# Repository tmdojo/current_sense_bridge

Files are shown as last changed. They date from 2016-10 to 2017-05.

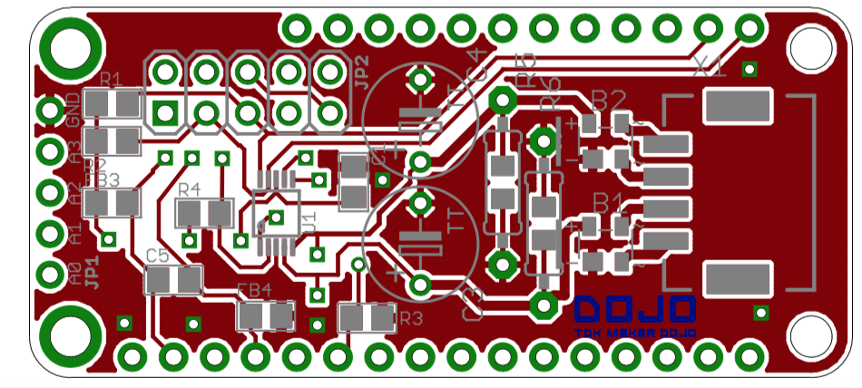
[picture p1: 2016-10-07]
TMdojo-Current-Sensor_v0p2_layoutA.png

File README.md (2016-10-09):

# Diode bridge rectifier and ADC break out board for clamp current sensors

This is designed for clamp current sensors such as:

TDK Corporation CCT261631-30-06-02
http://www.digikey.com/product-detail/en/tdk-corporation/CCT261631-30-06-02/445-172911-ND/5126210

The board is designed to fit nicely on Adafruit Feather line of products.
It also fit on Raspberry Pi although only ten pins are brokenout.
Mount it on a breadboard and you could combine it with many other microcontrollers such as Arduino Uno, MBED, etc

ADC part of the schematics and symbols are derived from the Adafruit 12 and 16 bit I2C ADC's with PGA.
https://github.com/adafruit/ADS1X15-Breakout-Board-PCBs

Please find the original readme text attached below.

----
This is the PCB for the Adafruit 12 and 16 bit I2C ADC's with PGA
Format is EagleCAD schematic and board layout

For more details, check out the product page at

-----> http://adafruit.com/products/1083
-----> http://adafruit.com/products/1085

Adafruit invests time and resources providing this open source design,
please support Adafruit and open-source hardware by purchasing
products from Adafruit!

Designed by Adafruit Industries.  
Creative Commons Attribution, Share-Alike license, check license.txt for more information
All text above must be included in any redistribution

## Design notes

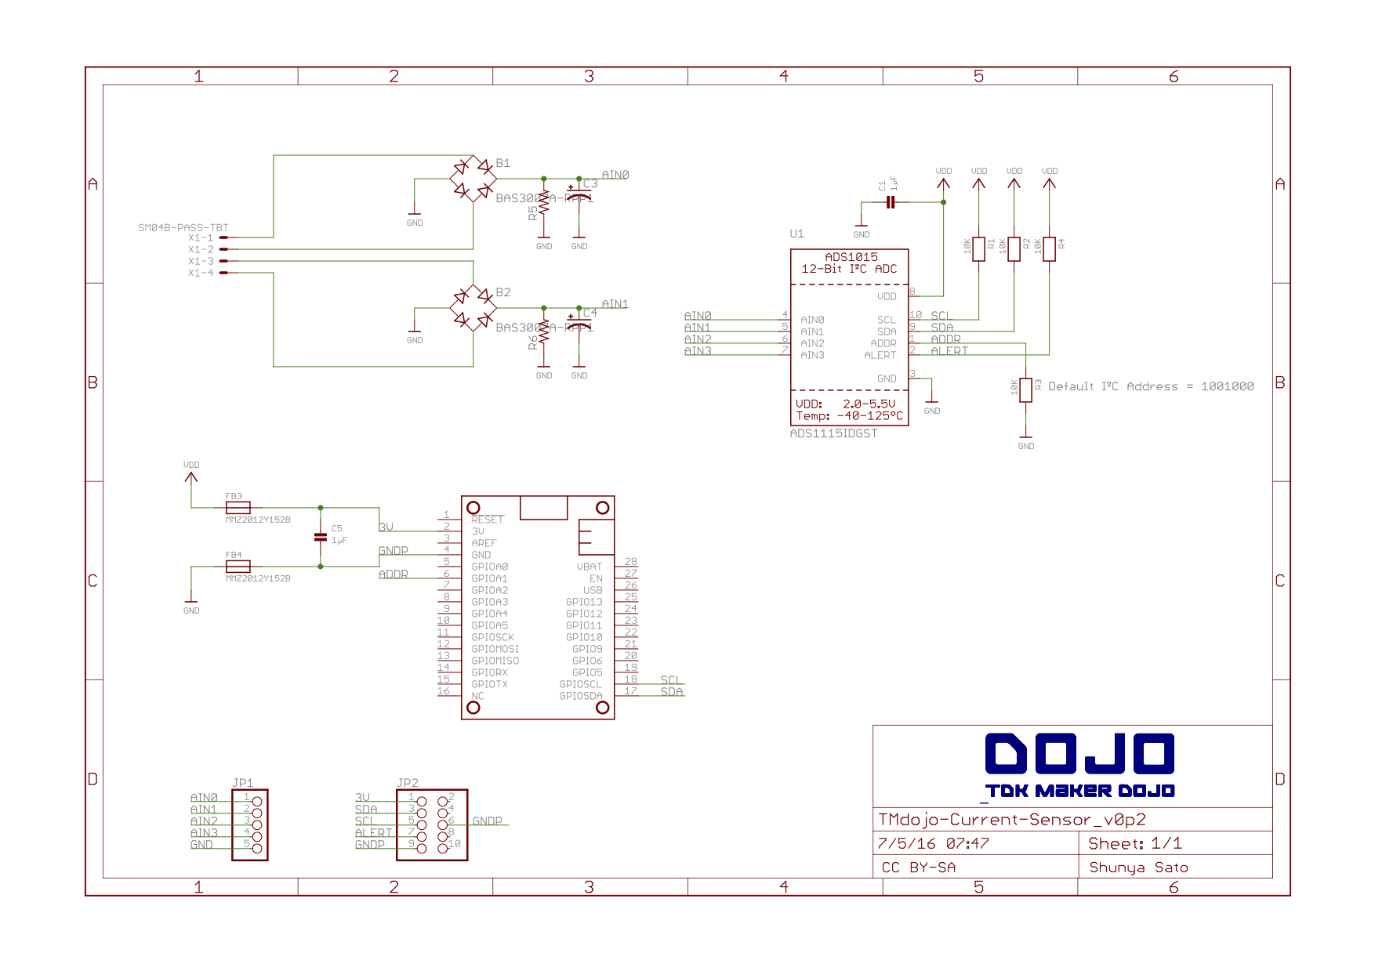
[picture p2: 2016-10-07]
TMdojo-Current-Sensor_v0p2_schematics.png

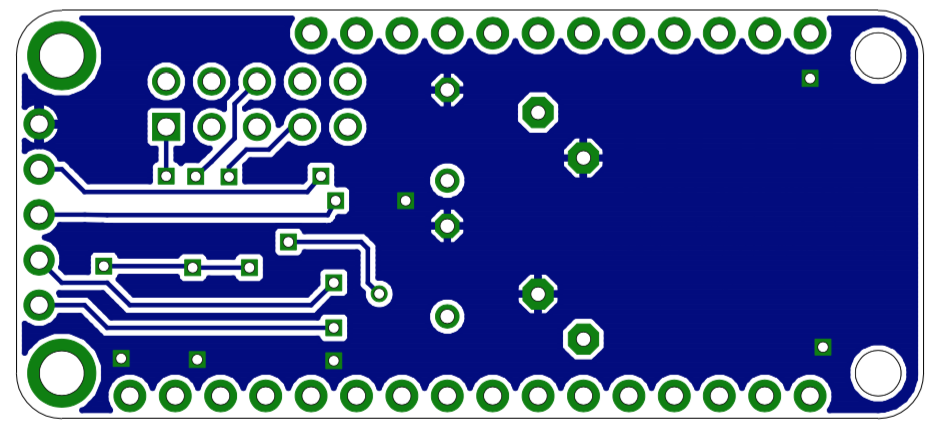
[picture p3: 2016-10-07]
TMdojo-Current-Sensor_v0p2_layoutB.png

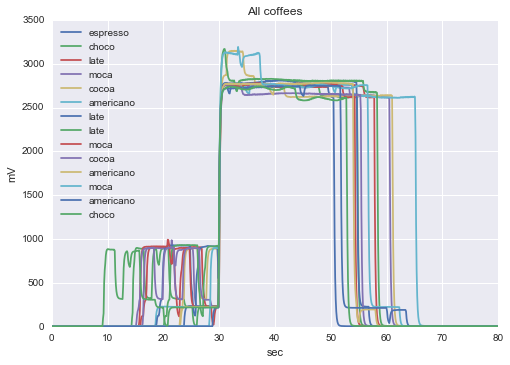
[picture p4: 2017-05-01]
images/coffee.png

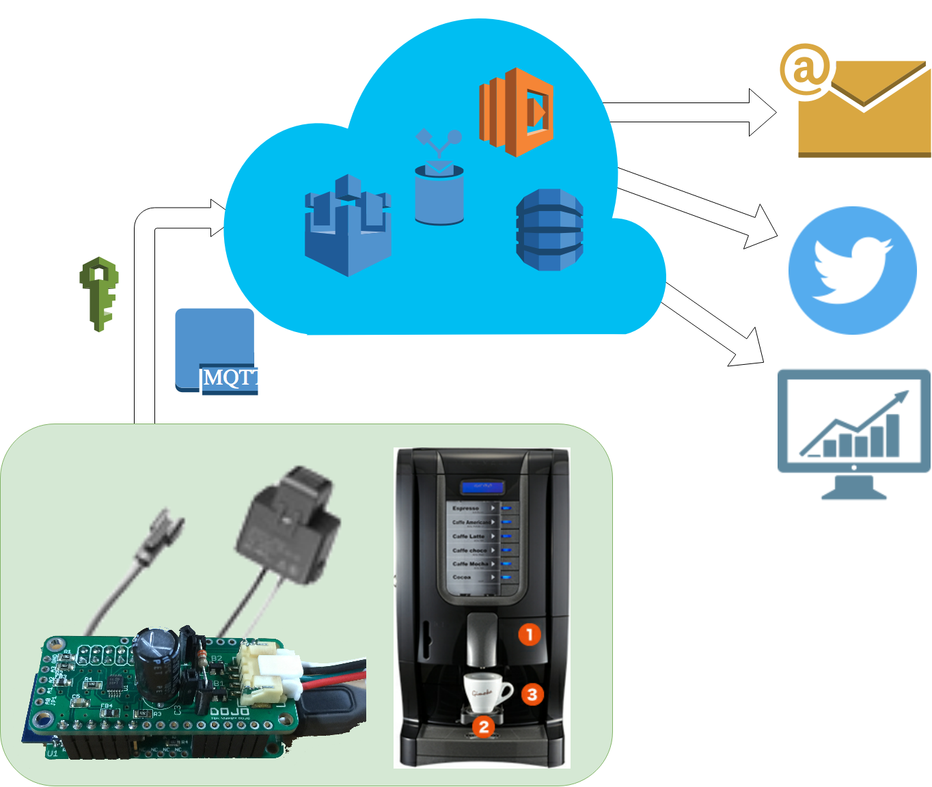
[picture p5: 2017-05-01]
images/current_monitoring.png

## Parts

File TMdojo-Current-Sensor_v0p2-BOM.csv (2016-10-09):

Part/Designator | Manufacture Part Number/Seeed SKU | Quantity | Digikey Part Number | Digikey Web Link | Note
U1 | ADS1015IDGST | 1 | 296-25227-1-ND | http://www.digikey.com/product-detail/en/texas-instruments/ADS1015IDGST/296-25227-1-ND/2174997
X2 | SM04B-PASS-TBT(LF)(SN) | 1 | 455-2645-1-ND | http://www.digikey.com/product-detail/en/jst-sales-america-inc/SM04B-PASS-TBT(LF)(SN)/455-2645-1-ND/2773441
B1, B2 | BAS 3007A-RPP E6327 | 2 | BAS3007A-RPPE6327INCT-ND | http://www.digikey.com/product-search/en/discrete-semiconductor-products/bridge-rectifiers/1377580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
C1, C5 | CC0805KKX7R8BB105/302010179 | 2 | 311-1456-1-ND | http://www.digikey.com/product-search/en/capacitors/ceramic-capacitors/131083?k=CC0805KKX7R8BB105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 | 1uF 0805
R1, R2, R3, R4 | RC0805FR-0710KL/301010361 | 4 | 311-10.0KCRCT-ND | http://www.digikey.com/product-search/en/resistors/chip-resistor-surface-mount/65769?k=RC0805FR-0710KL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 | 10k 0805
FB3, FB4 | MMZ2012Y152BT000 | 2 | 445-1560-1-ND | http://www.digikey.com/product-detail/en/tdk-corporation/MMZ2012Y152BT000/445-1560-1-ND/571890 | FERRITE BEAD 1.5 KOHM 0805 1LN
R5, R6 | Non-Fit 300 Ohm | 2
C3, C4 | Non-Fit 220uF | 2 | 493-6096-1-ND | https://www.digikey.jp/product-detail/ja/nichicon/UVR1C221MED1TA/493-6096-1-ND/3438470 | 7mmで220uFだと耐圧が16Vになっちゃう。25Vだと150uFが最大。経8mmだと220uFで25vある。
JP1, JP2, MS1 | Non-Fit | 0

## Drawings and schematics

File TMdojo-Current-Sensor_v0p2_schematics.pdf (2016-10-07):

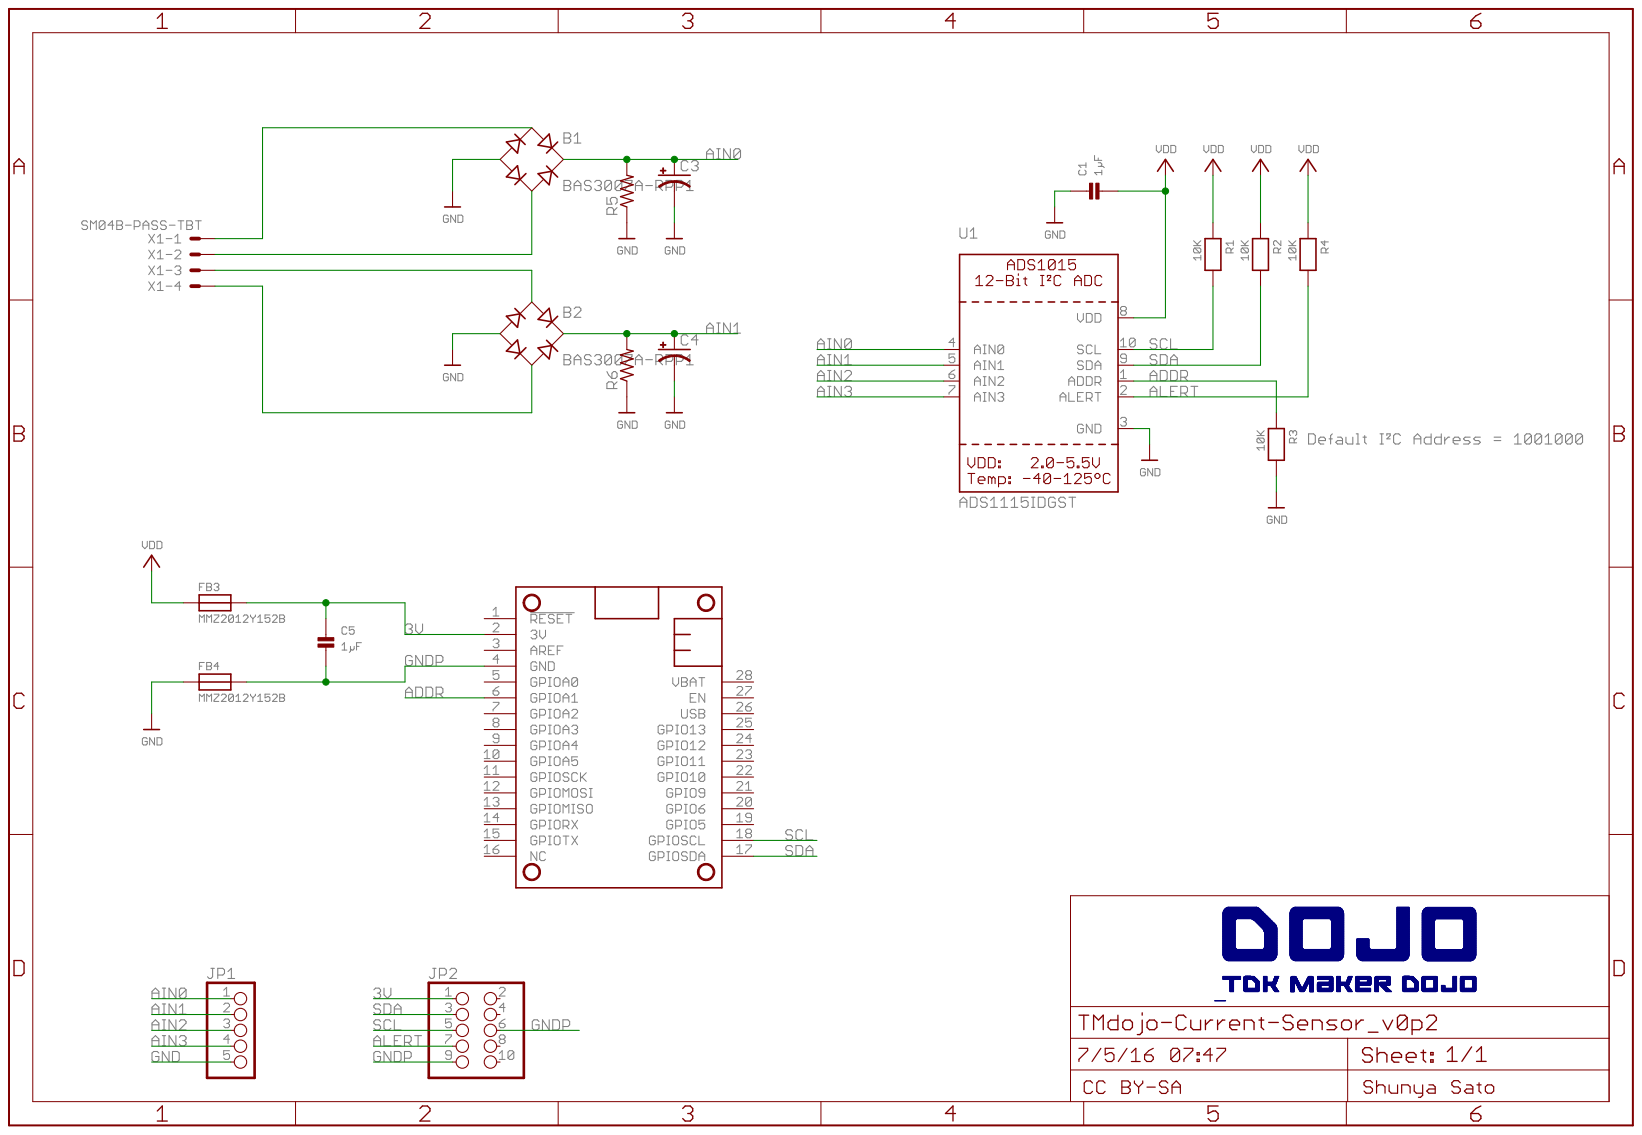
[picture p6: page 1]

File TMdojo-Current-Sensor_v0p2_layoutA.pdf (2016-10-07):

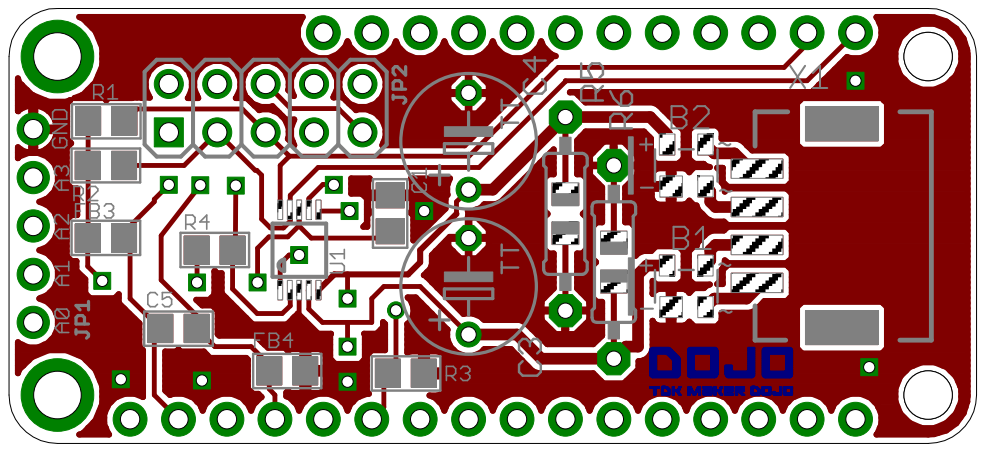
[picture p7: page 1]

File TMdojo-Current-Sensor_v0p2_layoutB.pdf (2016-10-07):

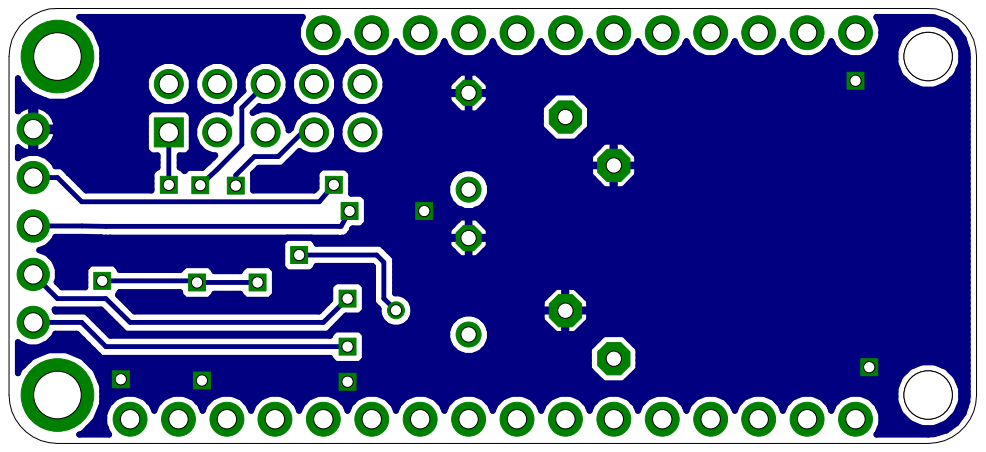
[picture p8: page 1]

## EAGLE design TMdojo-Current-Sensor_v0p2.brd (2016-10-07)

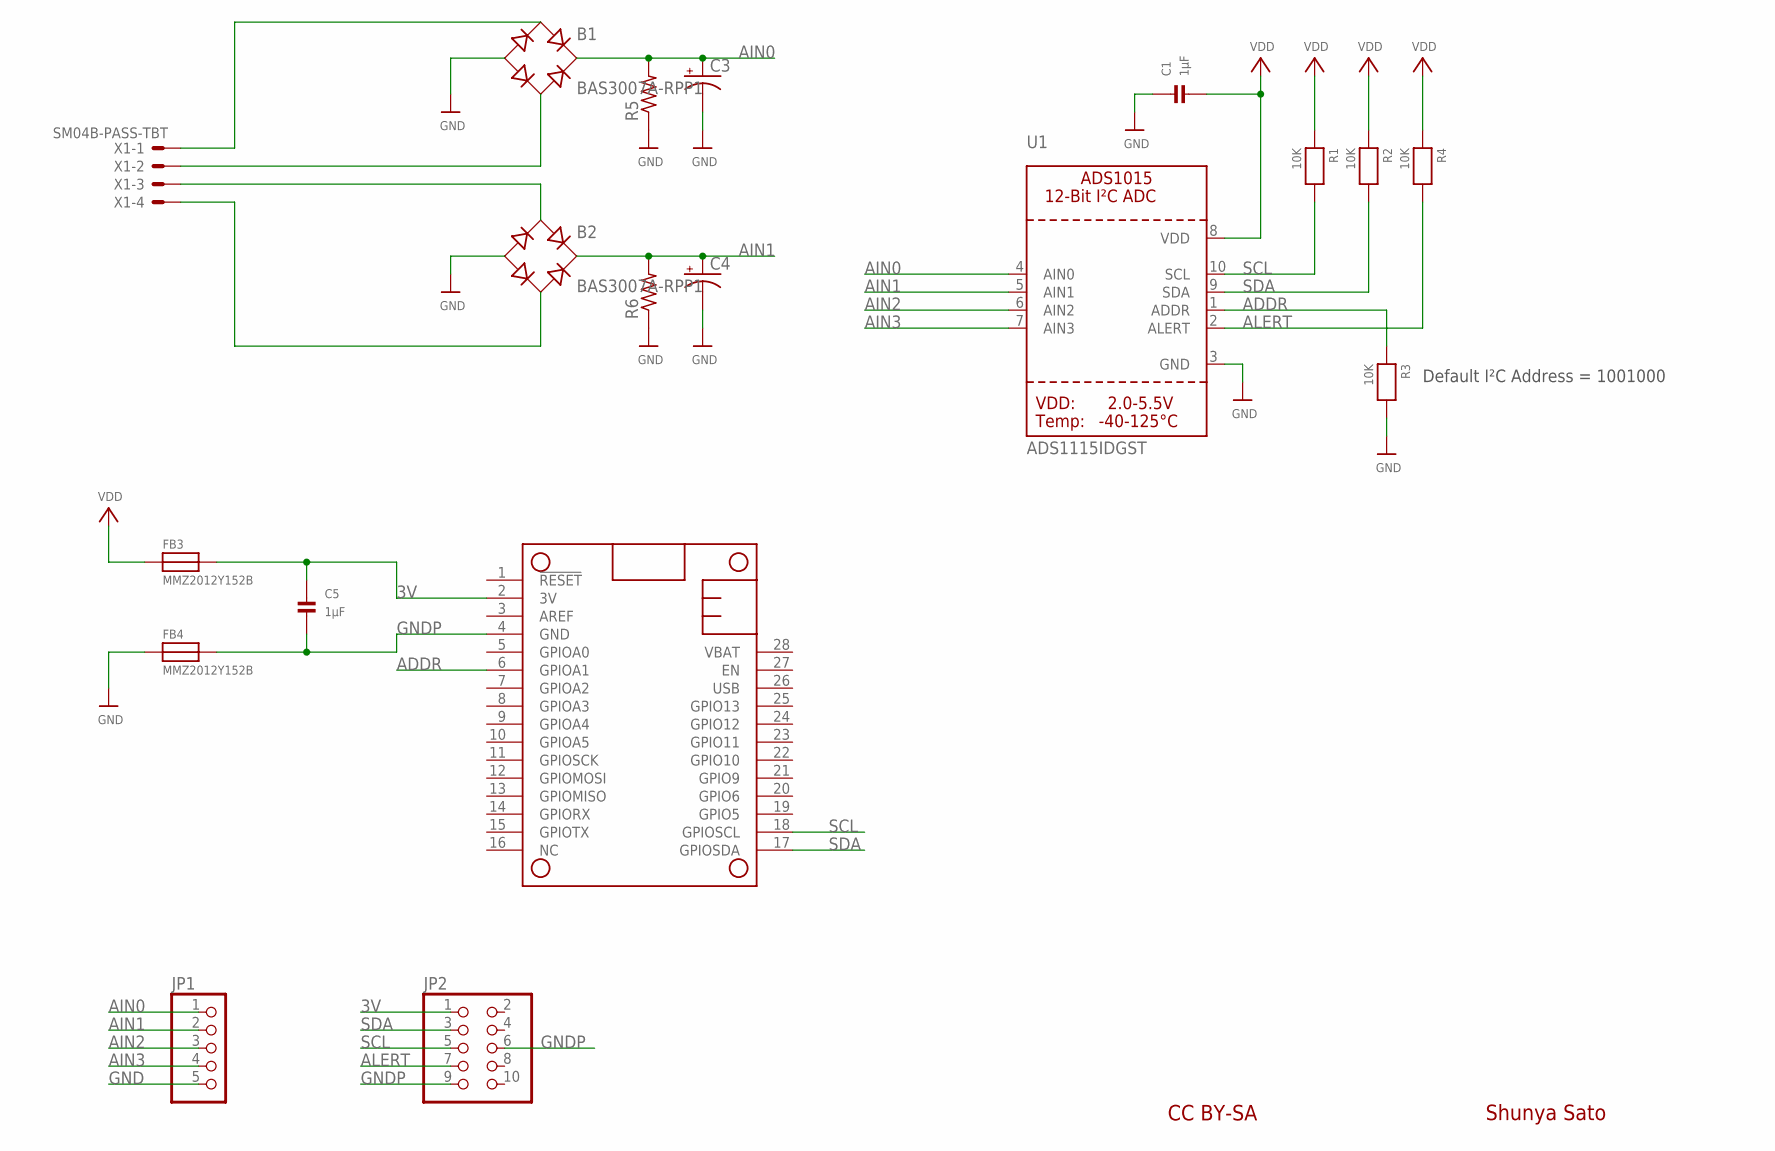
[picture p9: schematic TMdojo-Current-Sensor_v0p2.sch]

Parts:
B1, B2: BAS3007A-RPP1; SOT143
C1, C5: 1µF; 0805
C3, C4: CPOL-USTT5D7; TT5D7
FB3, FB4: MMZ2012Y152B; 0805
JP1: HEADER-1X5ROUND; 1X05_ROUND
JP2: HEADER-2X5; 2X05
MS1: FEATHERWING
R1, R2, R3, R4: 10K; 0805
R5, R6: R-US_FLIPFLOP; 0805-THM
U1: ADS1115IDGST; MSOP10
X1: SM04B-PASS-TBT

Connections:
3V: C5.1, FB3.2, JP2.1, MS1.2 (3V)
ADDR: MS1.6 (GPIOA1), R3.1, U1.1 (ADDR)
AIN0: B1.+, C3.+, JP1.1, R5.2, U1.4 (AIN0)
AIN1: B2.+, C4.+, JP1.2, R6.2, U1.5 (AIN1)
AIN2: JP1.3, U1.6 (AIN2)
AIN3: JP1.4, U1.7 (AIN3)
ALERT: JP2.7, R4.2, U1.2 (ALERT)
GND: B1.-, B2.-, C1.1, C3.-, C4.-, FB4.1, JP1.5, R3.2, R5.1, R6.1, U1.3 (GND)
GNDP: C5.2, FB4.2, JP2.6, JP2.9, MS1.4 (GND)
unnamed: B1.~1 (AC1), X1.1
unnamed: B1.~2 (AC2), X1.2
unnamed: B2.~1 (AC1), X1.3
unnamed: B2.~2 (AC2), X1.4
SCL: JP2.5, MS1.18 (GPIOSCL), R1.2, U1.10 (SCL)
SDA: JP2.3, MS1.17 (GPIOSDA), R2.2, U1.9 (SDA)
VDD: C1.2, FB3.1, R1.1, R2.1, R4.1, U1.8 (VDD)

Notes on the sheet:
Default I²C Address = 1001000
Shunya Sato
CC BY-SA

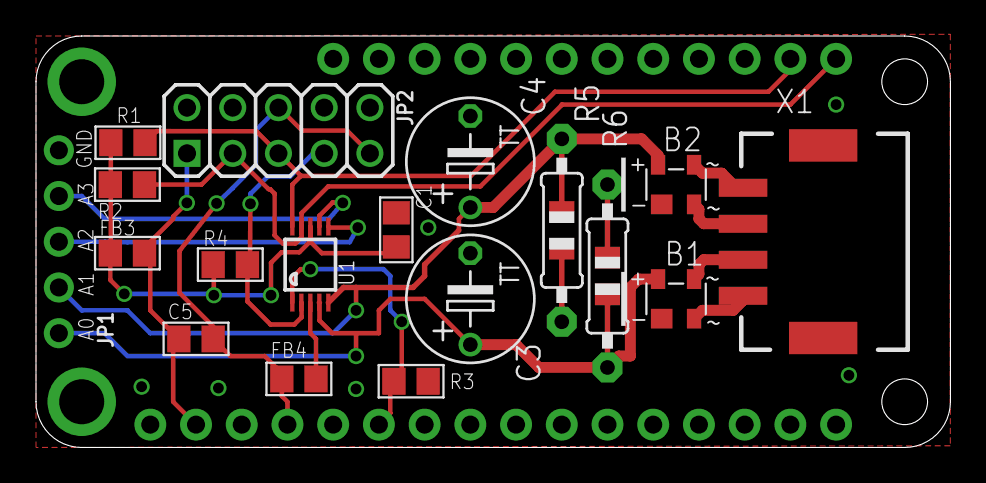
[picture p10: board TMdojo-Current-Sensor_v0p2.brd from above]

Board: 2 copper layers, 50.8 x 22.9 mm, 19 parts (0 on the bottom side), 16 nets.

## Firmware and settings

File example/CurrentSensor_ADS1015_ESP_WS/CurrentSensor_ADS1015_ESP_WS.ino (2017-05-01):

/*
current_sense_bridge example code

This code demonstrates how to read data from ADS1015 ADC on the current_sense_bridge board.

You need to install ADS1X15 Arduino library written by Adafruit Industries
https://github.com/adafruit/Adafruit_ADS1X15
Significant portion of this code was taken from the example included in the library.

This code is largely based on WebSocketServer_LEDcontrol.ino
https://github.com/Links2004/arduinoWebSockets

Run ESP-8266 with this sketch, access from your Mac or iPhone at this URL
http://esp-ct.local
You would see live update of data with plot

Author: Shunya Sato

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
*/

// #include <Arduino.h>

#include <ESP8266WiFi.h>
#include <ESP8266WiFiMulti.h>
#include <WebSocketsServer.h>
#include <ESP8266WebServer.h>
#include <ESP8266mDNS.h>
#include <Hash.h>

#include <Wire.h>
#include <Adafruit_ADS1015.h>
#include "Timer.h"

#define USE_SERIAL Serial


ESP8266WiFiMulti WiFiMulti;

ESP8266WebServer server = ESP8266WebServer(80);
WebSocketsServer webSocket = WebSocketsServer(81);

void webSocketEvent(uint8_t num, WStype_t type, uint8_t * payload, size_t lenght) {

    switch(type) {
        case WStype_DISCONNECTED:
            USE_SERIAL.printf("[%u] Disconnected!\n", num);
            break;
        case WStype_CONNECTED: {
            IPAddress ip = webSocket.remoteIP(num);
            USE_SERIAL.printf("[%u] Connected from %d.%d.%d.%d url: %s\n", num, ip[0], ip[1], ip[2], ip[3], payload);

            // send message to client
            webSocket.sendTXT(num, "Connected");
        }
            break;
        case WStype_TEXT:
            USE_SERIAL.printf("[%u] get Text: %s\n", num, payload);
            break;
    }

}

Timer t;
//Adafruit_ADS1115 ads;
Adafruit_ADS1015 ads;

// const float multiplier = 3.0F; /* ADS1015  @ 2/3x gain +/- 6.144V (12-bit results) */
const float multiplier = 2.0F; /* ADS1015  @ 1x gain   +/- 4.096V (12-bit results) */
// const float multiplier = 1.0F; /* ADS1015  @ 2x gain   +/- 2.048V (12-bit results) */
// const float multiplier = 0.5F; /* ADS1015  @ 4x gain   +/- 1.024V (12-bit results) */
// const float multiplier = 0.25F; /* ADS1015  @ 8x gain   +/- 0.512V (12-bit results) */
// const float multiplier = 0.125F; /* ADS1015  @ 16x gain  +/- 0.256V (12-bit results) */

void readADC(){
  int16_t adc0;
  int16_t adc1;

  adc0 = ads.readADC_SingleEnded(0);
  adc1 = ads.readADC_SingleEnded(1);

  Serial.print(millis());
  Serial.print(", ");
  Serial.print(adc0);
  Serial.print(", ");
  Serial.print(adc0 * multiplier);
  Serial.print(", ");
  Serial.print(adc1);
  Serial.print(", ");
  Serial.println(adc1 * multiplier);

  String tmp = String(adc1*multiplier);

  webSocket.broadcastTXT(tmp);
  
}

void setup() {
    USE_SERIAL.begin(115200);

    USE_SERIAL.println();
    USE_SERIAL.println();
    USE_SERIAL.println();

    for(uint8_t t = 4; t > 0; t--) {
        USE_SERIAL.printf("[SETUP] BOOT WAIT %d...\n", t);
        USE_SERIAL.flush();
        delay(1000);
    }

    WiFiMulti.addAP(“SSID", “password");
    WiFiMulti.addAP(“SSID2", “password");
    
    while(WiFiMulti.run() != WL_CONNECTED) {
        delay(100);
    }

    // start webSocket server
    webSocket.begin();
    webSocket.onEvent(webSocketEvent);

    if(MDNS.begin("esp-ct")) {
        USE_SERIAL.println("MDNS responder started");
    }

    // handle index
    server.on("/", []() {
        // send index.html
        server.send(200, "text/html", "<html><head><script type='text/javascript' src='https://cdnjs.cloudflare.com/ajax/libs/smoothie/1.27.0/smoothie.js'></script></head><body>Current sensor reading: <span id='nowvalue'></span><br/><br/><canvas id='mycanvas' width='400' height='100'></canvas><script>var smoothie = new SmoothieChart({  grid: { strokeStyle:'rgb(125, 125, 125)', fillStyle:'rgb(60, 0, 0)',          lineWidth: 1, millisPerLine: 250, verticalSections: 6, },  labels: { fillStyle:'rgb(255, 255, 0)' }});smoothie.streamTo(document.getElementById('mycanvas'), 100 /*delay*/);var line1 = new TimeSeries();setInterval(function() {  line1.append(new Date().getTime(), Math.random());}, 1000);smoothie.addTimeSeries(line1,  { strokeStyle:'rgb(0, 255, 0)', fillStyle:'rgba(0, 255, 0, 0.4)', lineWidth:3 });var connection = new WebSocket('ws://'+location.hostname+':81/', ['arduino']);connection.onopen = function () {  connection.send('Connect ' + new Date());};connection.onerror = function (error) {  console.log('WebSocket Error ', error);};connection.onmessage = function (e) {  console.log('Server: ', e.data);  line1.append(new Date().getTime(), parseFloat(e.data));  document.getElementById('nowvalue').innerHTML = e.data;};</script></body></html>");
    });

    server.begin();

    // Add service to MDNS
    MDNS.addService("http", "tcp", 80);
    MDNS.addService("ws", "tcp", 81);

  //Serial.println("Getting single-ended readings from AIN0..3");
  //Serial.println("ADC Range: +/- 6.144V (1 bit = 3mV/ADS1015, 0.1875mV/ADS1115)");

  // The ADC input range (or gain) can be changed via the following
  // functions, but be careful never to exceed VDD +0.3V max, or to
  // exceed the upper and lower limits if you adjust the input range!
  // Setting these values incorrectly may destroy your ADC!

  //                                                                ADS1015  ADS1115
  //                                                                -------  -------
  // ads.setGain(GAIN_TWOTHIRDS);  // 2/3x gain +/- 6.144V  1 bit = 3mV      0.1875mV (default)
  ads.setGain(GAIN_ONE);        // 1x gain   +/- 4.096V  1 bit = 2mV      0.125mV
  // ads.setGain(GAIN_TWO);        // 2x gain   +/- 2.048V  1 bit = 1mV      0.0625mV
  // ads.setGain(GAIN_FOUR);       // 4x gain   +/- 1.024V  1 bit = 0.5mV    0.03125mV
  // ads.setGain(GAIN_EIGHT);      // 8x gain   +/- 0.512V  1 bit = 0.25mV   0.015625mV
  // ads.setGain(GAIN_SIXTEEN);    // 16x gain  +/- 0.256V  1 bit = 0.125mV  0.0078125mV

  ads.begin();
  //ads.begin(4,5);
  /* Use this to set data rate for the 16-bit version (optional)*/
  //ads.setSPS(ADS1115_DR_860SPS);                      // for ADS1115 fastest samples per second is 860 (default is 128)

  // t.every(10, readADC); // 10ms interval = 100Hz
  // t.every(20, readADC); // 20ms interval = 50Hz
  t.every(100, readADC); // 100ms interval = 10Hz
}

void loop() {
    webSocket.loop();
    server.handleClient();
    t.update();
}

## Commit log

2016-10-07 v0p2 is the first fabricated design.
    [TMdojo-Current-Sensor_v0p2.brd, TMdojo-Current-Sensor_v0p2.sch]
2016-10-09 Add example Arduino sketch and BOM csv
    [TMdojo-Current-Sensor_v0p2-BOM.csv]
2016-11-01 Add comment that it uses timer library
2017-05-01 Add current monitor image for various coffee
